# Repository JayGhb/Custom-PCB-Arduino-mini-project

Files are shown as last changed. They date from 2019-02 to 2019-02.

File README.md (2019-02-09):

# Custom-PCB-Arduino-mini-project
Logging data, collected from custom pcb board, into SD card, using Arduino Pro mini.

The custom PCB is a break-out board for a lux, temperature and a humidity sensor, created with EAGLE 9.1.3
The ICs used are:
  * [TSL2561](https://cdn-shop.adafruit.com/datasheets/TSL2561.pdf) Lux sensor
  * [TMP102](http://www.ti.com/lit/ds/symlink/tmp102.pdf) Temperature sensor
  * [Si7021](https://www.silabs.com/documents/public/data-sheets/Si7021-A20.pdf) Humidity sensor

The project implements two I2C intefaces. The default Arduino Pro mini hardware one and a software I2C inteface using [SoftwareWire](https://github.com/Testato/SoftwareWire) with pins (8,9) as SDA, SCL respectively.

## JASON_TSL2561
A custom modification of the [Adafruit tsl2561 library](https://github.com/adafruit/TSL2561-Arduino-Library) is also implemented under
the JASON_TSL2561 folder, to be able to use the convenient provided functions with the SoftwareWire library.

### Other parts used
  1. Arduino Pro mini
  1. [MicroSD breakout board](https://www.sparkfun.com/products/544?_ga=2.162410361.45600573.1549733271-2101103923.1549733271)
  
Image of the board before ratsnest:

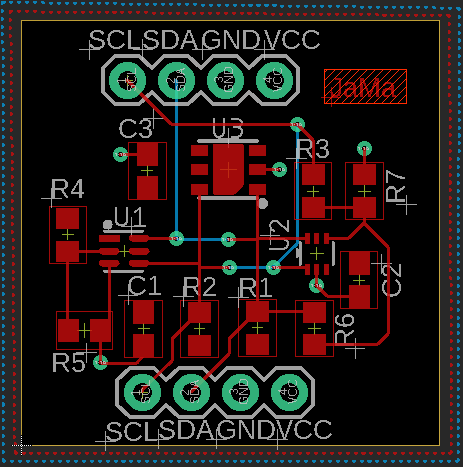
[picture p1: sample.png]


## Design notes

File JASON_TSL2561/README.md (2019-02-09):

# JASON_TSL2561 library
This library is a copy of the [Adafruit_TSL2561 library](https://github.com/adafruit/Adafruit_TSL2561) 
with minor changes, in order to be able to use the convinient functions provided in it with a Software I2C
interface instead of the default Arduino hardware one.

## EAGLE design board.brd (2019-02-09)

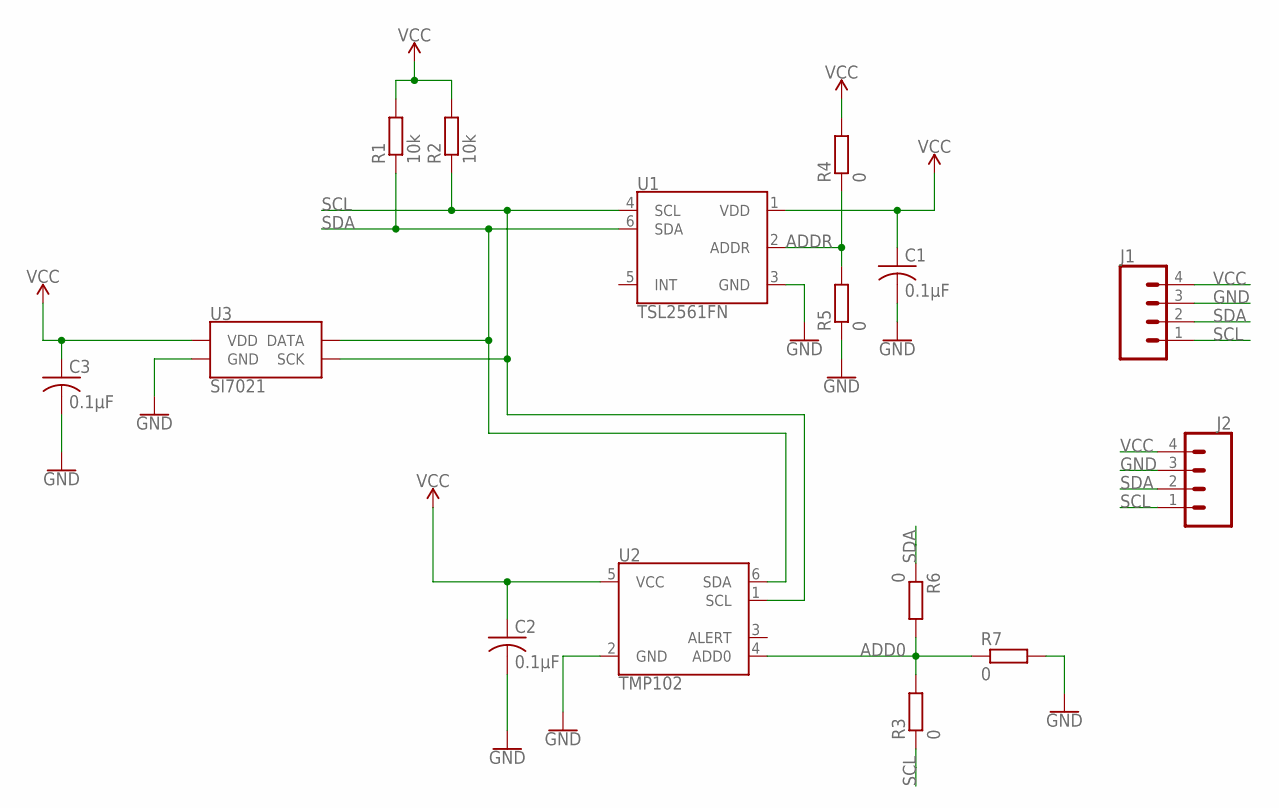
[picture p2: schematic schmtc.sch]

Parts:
C1, C2, C3: 0.1μF; C0603
J1, J2: CONN_04; 1X04
R1, R2: 10k; R0603
R3, R4, R5, R6, R7: 0; R0603
U1: TSL2561FN; DFN-6-2X2
U2: TMP102; SOT563
U3: SI7021; DFN-6-3X3-SI7021

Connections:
ADD0: R3.2, R6.2, R7.1, U2.4 (ADD0)
ADDR: R4.1, R5.2, U1.2 (ADDR)
GND: C1.2, C2.2, C3.2, J1.3, J2.3, R5.1, R7.2, U1.3 (GND), U2.2 (GND), U3.GND
SCL: J1.1, J2.1, R2.1, R3.1, U1.4 (SCL), U2.1 (SCL), U3.SCK
SDA: J1.2, J2.2, R1.1, R6.1, U1.6 (SDA), U2.6 (SDA), U3.DATA
VCC: C1.1, C2.1, C3.1, J1.4, J2.4, R1.2, R2.2, R4.2, U1.1 (VDD), U2.5 (VCC), U3.VDD

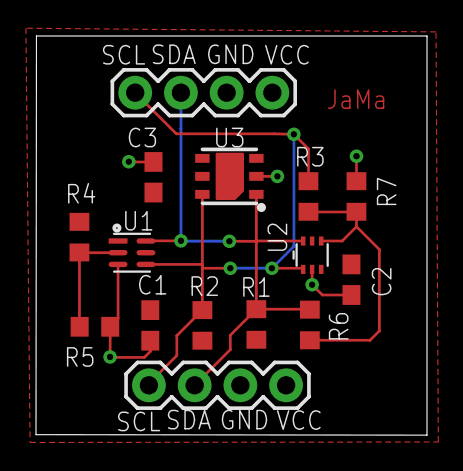
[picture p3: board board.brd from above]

Board: 2 copper layers, 21.7 x 22.2 mm, 15 parts (0 on the bottom side), 6 nets.

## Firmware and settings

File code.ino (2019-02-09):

/* 
  * A modification of the Adafruit_TSL2561_U library is
  * included under the name JASON_TSL2561_U . The modification
  * took place in order to be able to use the convenient 
  * functions provided in the Adafruit library with the
  * SoftwareWire I2C instance.
  * 
  * The aim of the project is to collect data (temperature, lux
  * humidity) using the custom made board. 
  * Collected data are logged into an SD card.
  * 
  * @author Jason Manoloudis
  *
*/

#include <Wire.h>
#include <Adafruit_Sensor.h>
#include <JASON_TSL2561_U.h>
#include <SPI.h>
#include "SparkFunTMP102.h"
#include "Adafruit_Si7021.h"
#include <SoftwareWire.h>
#include <Adafruit_TSL2561_U.h>
#include <SD.h>
#include <string.h>

//Instances with I2C addresses, where applicable
Adafruit_TSL2561_Unified tsl = Adafruit_TSL2561_Unified(TSL2561_ADDR_FLOAT, 1); 
Adafruit_TSL2561_Unified tsl2 = Adafruit_TSL2561_Unified(TSL2561_ADDR_LOW, 2); // R5 GND
Adafruit_TSL2561_Unified tsl3 = Adafruit_TSL2561_Unified(TSL2561_ADDR_HIGH, 3); // R4 VCC
TMP102 tmp(0x48); // R7 GND
TMP102 tmp2(0x4B); //R3 SCL
TMP102 tmp3(0x4A); //R6 SDA
Adafruit_Si7021 si7021 = Adafruit_Si7021();

SoftwareWire myWire(8,9);

JASON_TSLJASON_Unified tslll = JASON_TSLJASON_Unified(TSL2561_ADDR_FLOAT,4);
JASON_TSLJASON_Unified tslll2 = JASON_TSLJASON_Unified(TSL2561_ADDR_HIGH,5); //R4 VCC
TMP102 tmppp(0x48); // R7 GND
TMP102 tmppp2(0x4B); //R3 SCL


float temperature;
long lux;
float humidity;
char dataString[81] = "";
const int CSpin = 10; //SD breakout board Chip Select
File root;
String newestName;
long converted;


/* @brief: save data in SD
 * @param filename: the name of file to save into
 * @param dtString: the char array to be written in file
*/
void saveData(String filename, char dtString[])
{
  File file = SD.open(filename,FILE_WRITE);
 // Serial.print(F("FreeRam: "));Serial.println(FreeRam());
  if(file)
  {
    file.print(dtString);
    file.close();
  }else
  {
    //Serial.println(F("Error writing in file"));
    while(1);
  }
}

/* @brief: Count the number of existing files in SD to generate next file
 * @param root: the reference file  
 * @return newName: the name of the new file (num_of_files+1.csv)
*/
String countFiles(File root)
{
  int fileCounter = 0;
  while(1)
  {
    File file2 = root.openNextFile();
    if(!file2) 
    {
      String newName = "data" + String(fileCounter) + ".csv";
      return newName;
    }
    fileCounter ++;
    file2.close();
  }
}

/* Optional configuration settings */
void configure()
{
  tmp.setConversionRate(2);
  tmp.setExtendedMode(0);
  tmp2.setConversionRate(2);
  tmp2.setExtendedMode(0);
  tmp3.setConversionRate(2);
  tmp3.setExtendedMode(0);
  tsl.enableAutoRange(true); //Auto gain
  tsl.setIntegrationTime(TSL2561_INTEGRATIONTIME_402MS);
  tsl2.enableAutoRange(true); //Auto gain
  tsl2.setIntegrationTime(TSL2561_INTEGRATIONTIME_402MS); 
  tsl3.enableAutoRange(true); //Auto gain
  tsl3.setIntegrationTime(TSL2561_INTEGRATIONTIME_402MS);
}

void setup() 
{
  //Serial.begin(9600);
  if(!si7021.begin()) {/*Serial.println(F("Problem with si7021"));*/ while(true);}
  tmp.begin();
  tmp2.begin();
  tmp3.begin();
  if(!tsl.begin()) {/*Serial.println(F("Problem with tsl 1")); */ while(true);}
  if(!tsl2.begin()) {/*Serial.println(F("Problem with tsl 2")); */while(true);}
  if(!tsl3.begin()) {/*Serial.println(F("Problem with tsl 3"));*/ while(true);}

  myWire.begin();

  if(!tslll.begin(&myWire)) {/*Serial.println(F("problem with soft i2c tsl"));*/ while(true);}
  if(!tslll2.begin(&myWire)) {/*Serial.println(F("problem with soft i2c tsl 2")); */while(true);}
  
  configure();

  pinMode(CSpin, OUTPUT); //Set SD ChipSelect pin as output even if it is not used

  /* Generate new filename & add "headers" line */
  if(!SD.begin(CSpin)) {/*Serial.println(F("Card failed"));*/ while(1);}
  root = SD.open("/"); 
  newestName = countFiles(root);
  root.close();
  char firstRow[] = "temp1;temp2;temp3;temp4;temp5;hum;lux1;lux2;lux3;lux4;lux5;\n"; 
  saveData(newestName, firstRow);
}

/* @brief: convert float to char array and append it in dataString
 * @param f: the number to be converted & saved
*/
void changeToStringAndConcat(float f)
{
  char temp[12];
  dtostrf(f,6,2,temp);
  strcat(dataString, temp);
  strcat(dataString, ";");
}

void loop() 
{
  sensors_event_t event;
  sensors_event_t event2;
  sensors_event_t event3;
  sensors_event_t event10;
  sensors_event_t event11; 

 /* Hardware I2C TMP102 */
  tmp.wakeup();
  temperature = tmp.readTempC();
  tmp.sleep();
  changeToStringAndConcat(temperature);
  
  tmp2.wakeup();
  temperature = tmp2.readTempC();
  tmp2.sleep();
  changeToStringAndConcat(temperature);

  tmp3.wakeup();
  temperature = tmp3.readTempC();
  tmp3.sleep();
  changeToStringAndConcat(temperature);

  /* Software I2C TMP102 */
  myWire.beginTransmission(0x48);
  myWire.write(uint8_t(0x00));
  myWire.endTransmission();
  myWire.requestFrom(0x48, 2);
  byte c = myWire.read();
  byte c2 = myWire.read();
  int temp = (((c<<8)|c2)>>4) & 0xFFF;
  if(bitRead(temp,11)==1) //Negative value is denoted with MSB = 1
  {
    temp -= 0x1000;
  }
  float temp2 = temp*0.0625;
  changeToStringAndConcat(temp2);
  
  myWire.beginTransmission(0x4B);
  myWire.write(uint8_t(0x00));
  myWire.endTransmission();
  myWire.requestFrom(0x4B, 2);
  c = myWire.read();
  c2 = myWire.read();
  temp = (((c<<8)|c2)>>4) & 0xFFF;
  if(bitRead(temp,11)==1) //Negative value is denoted with MSB = 1
  {
    temp -= 0x1000;
  }
  temp2 = temp*0.0625;
  changeToStringAndConcat(temp2);

  /* read from Si7021 humidity sensor */
  humidity = si7021.readHumidity();
  changeToStringAndConcat(humidity);

  /* Hardware I2C TSL2561 */
  tsl.getEvent(&event);
  lux = (long)event.light;
  changeToStringAndConcat(lux);
 
  tsl2.getEvent(&event2);
  lux = (long)event2.light;
  changeToStringAndConcat(lux);

  tsl3.getEvent(&event3); 
  lux = (long)event3.light;
  changeToStringAndConcat(lux);
  
  /* Software I2C TSL2561 */
  tslll.getEvent(&event10);
  lux = (long)event10.light;
  changeToStringAndConcat(lux);
   
  tslll2.getEvent(&event11);
  lux = (long)event11.light;
  changeToStringAndConcat(lux);

  strcat(dataString, "\n");
  saveData(newestName,dataString);
  dataString[0]=(char)0;
  delay(2000);
}

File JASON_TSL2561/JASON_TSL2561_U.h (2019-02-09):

/*!
 * @file Adafruit_TSLJASON_U.h
 *
 * This is part of Adafruit's FXOS8700 driver for the Arduino platform.  It is
 * designed specifically to work with the Adafruit FXOS8700 breakout:
 * https://www.adafruit.com/products/3463
 *
 * These sensors use I2C to communicate, 2 pins (SCL+SDA) are required
 * to interface with the breakout.
 *
 * Adafruit invests time and resources providing this open source code,
 * please support Adafruit and open-source hardware by purchasing
 * products from Adafruit!
 *
 * Written by Kevin "KTOWN" Townsend for Adafruit Industries.
 *
 * BSD license, all text here must be included in any redistribution.
 *
 */

#ifndef JASON_TSLJASON_H_
#define JASON_TSLJASON_H_

#include <Arduino.h>
#include <Adafruit_Sensor.h>
#include <SoftwareWire.h>

#define TSLJASON_VISIBLE 2                   ///< channel 0 - channel 1
#define TSLJASON_INFRARED 1                  ///< channel 1
#define TSLJASON_FULLSPECTRUM 0              ///< channel 0

// I2C address options
#define TSLJASON_ADDR_LOW          (0x29)    ///< Default address (pin pulled low)
#define TSLJASON_ADDR_FLOAT        (0x39)    ///< Default address (pin left floating)
#define TSLJASON_ADDR_HIGH         (0x49)    ///< Default address (pin pulled high)

// Lux calculations differ slightly for CS package
//#define TSLJASON_PACKAGE_CS                ///< Chip scale package     
#define TSLJASON_PACKAGE_T_FN_CL             ///< Dual Flat No-Lead package

#define TSLJASON_COMMAND_BIT       (0x80)    ///< Must be 1
#define TSLJASON_CLEAR_BIT         (0x40)    ///< Clears any pending interrupt (write 1 to clear)
#define TSLJASON_WORD_BIT          (0x20)    ///< 1 = read/write word (rather than byte)
#define TSLJASON_BLOCK_BIT         (0x10)    ///< 1 = using block read/write

#define TSLJASON_CONTROL_POWERON   (0x03)    ///< Control register setting to turn on
#define TSLJASON_CONTROL_POWEROFF  (0x00)    ///< Control register setting to turn off

#define TSLJASON_LUX_LUXSCALE      (14)      ///< Scale by 2^14
#define TSLJASON_LUX_RATIOSCALE    (9)       ///< Scale ratio by 2^9
#define TSLJASON_LUX_CHSCALE       (10)      ///< Scale channel values by 2^10
#define TSLJASON_LUX_CHSCALE_TINT0 (0x7517)  ///< 322/11 * 2^TSLJASON_LUX_CHSCALE
#define TSLJASON_LUX_CHSCALE_TINT1 (0x0FE7)  ///< 322/81 * 2^TSLJASON_LUX_CHSCALE

// T, FN and CL package values
#define TSLJASON_LUX_K1T           (0x0040)  ///< 0.125 * 2^RATIO_SCALE
#define TSLJASON_LUX_B1T           (0x01f2)  ///< 0.0304 * 2^LUX_SCALE
#define TSLJASON_LUX_M1T           (0x01be)  ///< 0.0272 * 2^LUX_SCALE
#define TSLJASON_LUX_K2T           (0x0080)  ///< 0.250 * 2^RATIO_SCALE
#define TSLJASON_LUX_B2T           (0x0214)  ///< 0.0325 * 2^LUX_SCALE
#define TSLJASON_LUX_M2T           (0x02d1)  ///< 0.0440 * 2^LUX_SCALE
#define TSLJASON_LUX_K3T           (0x00c0)  ///< 0.375 * 2^RATIO_SCALE
#define TSLJASON_LUX_B3T           (0x023f)  ///< 0.0351 * 2^LUX_SCALE
#define TSLJASON_LUX_M3T           (0x037b)  ///< 0.0544 * 2^LUX_SCALE
#define TSLJASON_LUX_K4T           (0x0100)  ///< 0.50 * 2^RATIO_SCALE
#define TSLJASON_LUX_B4T           (0x0270)  ///< 0.0381 * 2^LUX_SCALE
#define TSLJASON_LUX_M4T           (0x03fe)  ///< 0.0624 * 2^LUX_SCALE
#define TSLJASON_LUX_K5T           (0x0138)  ///< 0.61 * 2^RATIO_SCALE
#define TSLJASON_LUX_B5T           (0x016f)  ///< 0.0224 * 2^LUX_SCALE
#define TSLJASON_LUX_M5T           (0x01fc)  ///< 0.0310 * 2^LUX_SCALE
#define TSLJASON_LUX_K6T           (0x019a)  ///< 0.80 * 2^RATIO_SCALE
#define TSLJASON_LUX_B6T           (0x00d2)  ///< 0.0128 * 2^LUX_SCALE
#define TSLJASON_LUX_M6T           (0x00fb)  ///< 0.0153 * 2^LUX_SCALE
#define TSLJASON_LUX_K7T           (0x029a)  ///< 1.3 * 2^RATIO_SCALE
#define TSLJASON_LUX_B7T           (0x0018)  ///< 0.00146 * 2^LUX_SCALE
#define TSLJASON_LUX_M7T           (0x0012)  ///< 0.00112 * 2^LUX_SCALE
#define TSLJASON_LUX_K8T           (0x029a)  ///< 1.3 * 2^RATIO_SCALE
#define TSLJASON_LUX_B8T           (0x0000)  ///< 0.000 * 2^LUX_SCALE
#define TSLJASON_LUX_M8T           (0x0000)  ///< 0.000 * 2^LUX_SCALE

// CS package values
#define TSLJASON_LUX_K1C           (0x0043)  ///< 0.130 * 2^RATIO_SCALE
#define TSLJASON_LUX_B1C           (0x0204)  ///< 0.0315 * 2^LUX_SCALE
#define TSLJASON_LUX_M1C           (0x01ad)  ///< 0.0262 * 2^LUX_SCALE
#define TSLJASON_LUX_K2C           (0x0085)  ///< 0.260 * 2^RATIO_SCALE
#define TSLJASON_LUX_B2C           (0x0228)  ///< 0.0337 * 2^LUX_SCALE
#define TSLJASON_LUX_M2C           (0x02c1)  ///< 0.0430 * 2^LUX_SCALE
#define TSLJASON_LUX_K3C           (0x00c8)  ///< 0.390 * 2^RATIO_SCALE
#define TSLJASON_LUX_B3C           (0x0253)  ///< 0.0363 * 2^LUX_SCALE
#define TSLJASON_LUX_M3C           (0x0363)  ///< 0.0529 * 2^LUX_SCALE
#define TSLJASON_LUX_K4C           (0x010a)  ///< 0.520 * 2^RATIO_SCALE
#define TSLJASON_LUX_B4C           (0x0282)  ///< 0.0392 * 2^LUX_SCALE
#define TSLJASON_LUX_M4C           (0x03df)  ///< 0.0605 * 2^LUX_SCALE
#define TSLJASON_LUX_K5C           (0x014d)  ///< 0.65 * 2^RATIO_SCALE
#define TSLJASON_LUX_B5C           (0x0177)  ///< 0.0229 * 2^LUX_SCALE
#define TSLJASON_LUX_M5C           (0x01dd)  ///< 0.0291 * 2^LUX_SCALE
#define TSLJASON_LUX_K6C           (0x019a)  ///< 0.80 * 2^RATIO_SCALE
#define TSLJASON_LUX_B6C           (0x0101)  ///< 0.0157 * 2^LUX_SCALE
#define TSLJASON_LUX_M6C           (0x0127)  ///< 0.0180 * 2^LUX_SCALE
#define TSLJASON_LUX_K7C           (0x029a)  ///< 1.3 * 2^RATIO_SCALE
#define TSLJASON_LUX_B7C           (0x0037)  ///< 0.00338 * 2^LUX_SCALE
#define TSLJASON_LUX_M7C           (0x002b)  ///< 0.00260 * 2^LUX_SCALE
#define TSLJASON_LUX_K8C           (0x029a)  ///< 1.3 * 2^RATIO_SCALE
#define TSLJASON_LUX_B8C           (0x0000)  ///< 0.000 * 2^LUX_SCALE
#define TSLJASON_LUX_M8C           (0x0000)  ///< 0.000 * 2^LUX_SCALE

// Auto-gain thresholds
#define TSLJASON_AGC_THI_13MS      (4850)    ///< Max value at Ti 13ms = 5047
#define TSLJASON_AGC_TLO_13MS      (100)     ///< Min value at Ti 13ms = 100
#define TSLJASON_AGC_THI_101MS     (36000)   ///< Max value at Ti 101ms = 37177
#define TSLJASON_AGC_TLO_101MS     (200)     ///< Min value at Ti 101ms = 200
#define TSLJASON_AGC_THI_402MS     (63000)   ///< Max value at Ti 402ms = 65535
#define TSLJASON_AGC_TLO_402MS     (500)     ///< Min value at Ti 402ms = 500

// Clipping thresholds
#define TSLJASON_CLIPPING_13MS     (4900)    ///< # Counts that trigger a change in gain/integration
#define TSLJASON_CLIPPING_101MS    (37000)   ///< # Counts that trigger a change in gain/integration
#define TSLJASON_CLIPPING_402MS    (65000)   ///< # Counts that trigger a change in gain/integration

// Delay for integration times
#define TSLJASON_DELAY_INTTIME_13MS    (15)    ///< Wait 15ms for 13ms integration
#define TSLJASON_DELAY_INTTIME_101MS   (120)   ///< Wait 120ms for 101ms integration
#define TSLJASON_DELAY_INTTIME_402MS   (450)   ///< Wait 450ms for 402ms integration
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

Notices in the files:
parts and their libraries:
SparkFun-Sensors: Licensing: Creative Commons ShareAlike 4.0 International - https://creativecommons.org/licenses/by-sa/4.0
